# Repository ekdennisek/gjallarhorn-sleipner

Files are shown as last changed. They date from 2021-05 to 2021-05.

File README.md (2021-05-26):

# Gjallarhorn Sleipner

## Introduction

**This code is currently under development, and is not ready to be used yet.**
See the [TODO section](#todo)

The Gjallarhorn Sleipner is an open source Eurorack compatible step sequencer. Powered by an Atmel AVR ATmega32
running at 16 MHz, it features 2 CV/gate channels and 6 gate only channels for controlling percussion or similar.

## Programming the MCU

The firmware may be built by simply running

    make

Once the firmware `main.hex` is built, upload it to the MCU and set the correct fuse bits. The example below uses
avrdude on a Raspberry Pi to program the MCU (make sure that your `avrdude.conf` is setup correctly according to the
pins being used)

    avrdude -c linuxgpio -p atmega32 -v -U flash:w:main.hex
    avrdude -c linuxgpio -p atmega32 -v -U hfuse:w:0xC9:m
    avrdude -c linuxgpio -p atmega32 -v -U lfuse:w:0xEF:m

Please note that you will have to connect a 16 MHz crystal to the ATmega32 in order to use it once the fuses have been
programmed.

## Technical specs

### Gates

All eight gate outputs are 12 V with an output impedance of roughly 470 ohm.

### Clock

The clock output is 5 V. Just like the gates, its output impedance is roughly 470 ohm.

### CV

The two CV outputs are 0 V - 10 V and follows the 1 V per octave standard. A C4 note corresponds to 4 V.

## Usage

TODO

## TODO

The list below is far from an exhaustive list of what's coming, but the main features for a 1.0.0 version should all be
listed.

* Documentation: Write a usage and improve the technical specs section
* Firmware: Read the input state of the two command buttons, fé and úr
* Firmware: Allow a user to change the channel, tempo and note of the CV channels
* Firmware: Allow a user to set gate duration as a percentage of a step

## Changelog

TODO once version 1.0.0 has been achieved.

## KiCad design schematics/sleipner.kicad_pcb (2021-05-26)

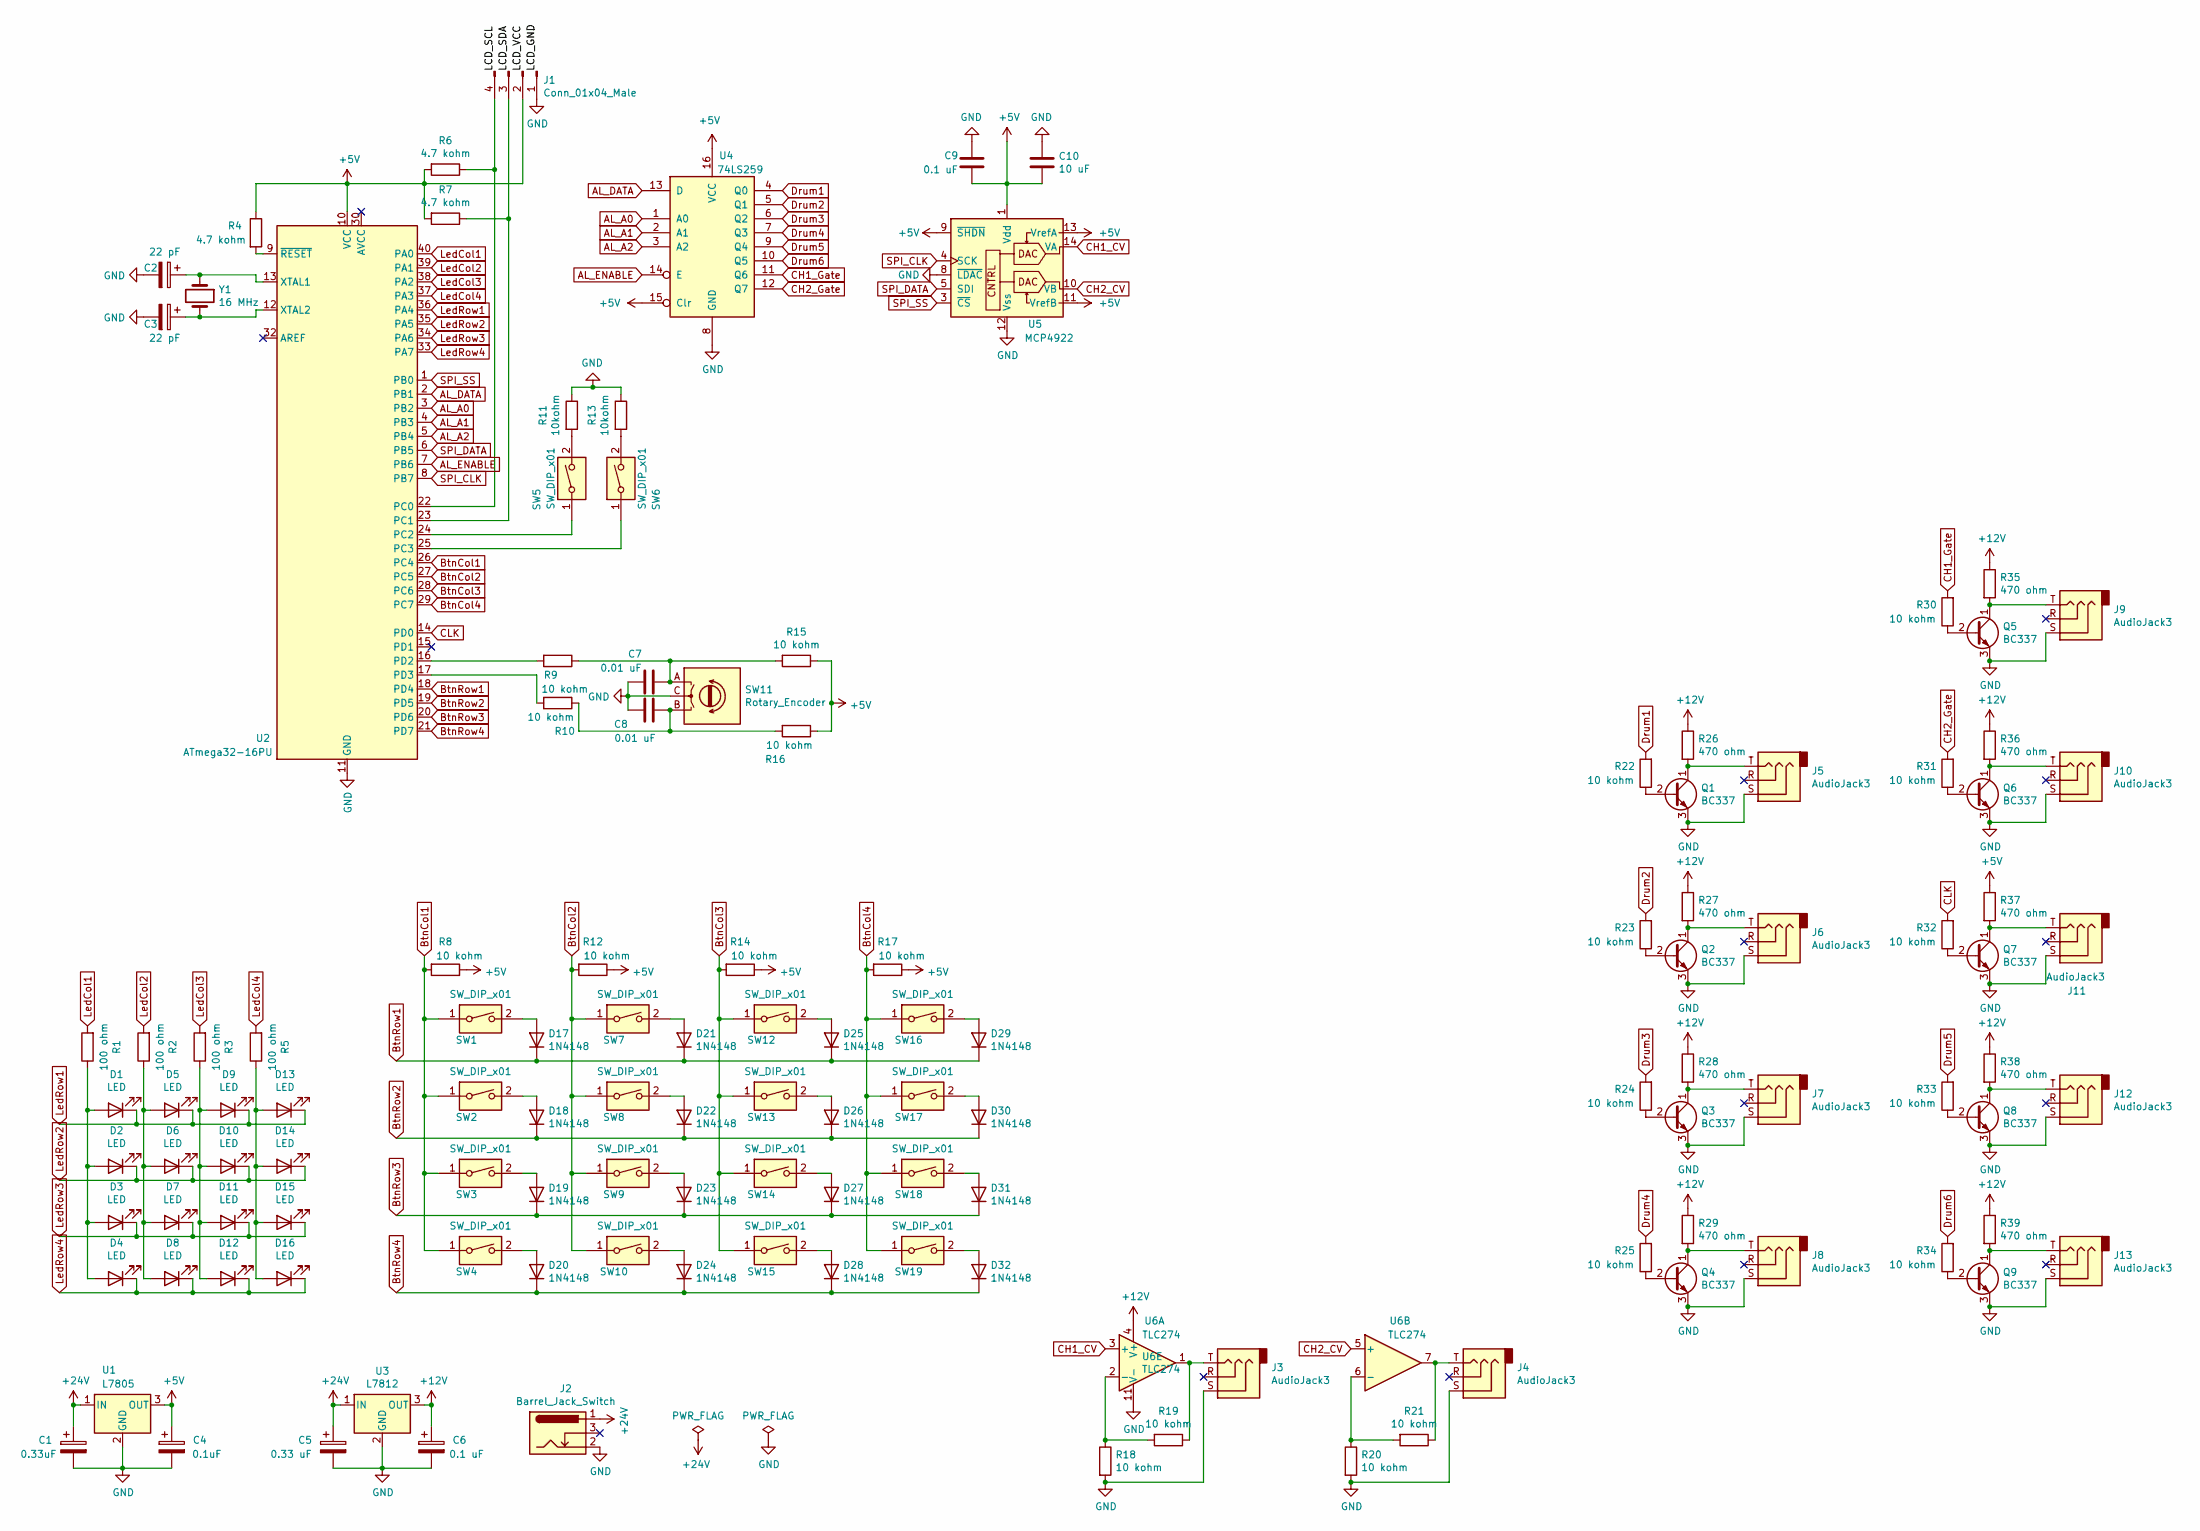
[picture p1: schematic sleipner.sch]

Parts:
C1: 0.33uF; CP_Radial_D5.0mm_P2.00mm
C2, C3: 22 pF; C_Disc_D5.0mm_W2.5mm_P5.00mm
C4: 0.1uF; C_Disc_D5.0mm_W2.5mm_P5.00mm
C5: 0.33 uF; CP_Radial_D5.0mm_P2.00mm
C6, C9: 0.1 uF; C_Disc_D5.0mm_W2.5mm_P5.00mm
C7, C8: 0.01 uF; C_Disc_D5.0mm_W2.5mm_P5.00mm
C10: 10 uF; CP_Radial_D5.0mm_P2.00mm
D1, D2, D3, D4, D5, D6, D7, D8, D9, D10, D11, D12, D13, D14, D15, D16: LED; LED_D3.0mm
D17, D18, D19, D20, D21, D22, D23, D24, D25, D26, D27, D28, D29, D30, D31, D32: 1N4148; D_DO-35_SOD27_P7.62mm_Horizontal
J1: Conn_01x04_Male; PinHeader_1x04_P2.54mm_Horizontal
J2: Barrel_Jack_Switch; BarrelJack_Horizontal
J3, J4, J5, J6, J7, J8, J9, J10, J11, J12, J13: AudioJack3; 3.55mmJack
Q1, Q2, Q3, Q4, Q5, Q6, Q7, Q8, Q9: BC337; TO-92_Inline
R1, R2, R3, R5: 100 ohm; R_Axial_DIN0309_L9.0mm_D3.2mm_P12.70mm_Horizontal
R4, R6, R7: 4.7 kohm; R_Axial_DIN0309_L9.0mm_D3.2mm_P12.70mm_Horizontal
R8, R9, R10, R12, R14, R15, R16, R17, R18, R19, R20, R21, R22, R23, R24, R25, R30, R31, R32, R33, R34: 10 kohm; R_Axial_DIN0309_L9.0mm_D3.2mm_P12.70mm_Horizontal
R11, R13: 10kohm; R_Axial_DIN0309_L9.0mm_D3.2mm_P12.70mm_Horizontal
R26, R27, R28, R29, R35, R36, R37, R38, R39: 470 ohm; R_Axial_DIN0309_L9.0mm_D3.2mm_P12.70mm_Horizontal
SW1, SW2, SW3, SW4, SW5, SW6, SW7, SW8, SW9, SW10, SW12, SW13, SW14, SW15, SW16, SW17, SW18, SW19: SW_DIP_x01; SW_PUSH-12mm
SW11: Rotary_Encoder; RotaryEncoder_Alps_EC12E_Vertical_H20mm
U1: L7805; TO-220-3_Horizontal_TabDown
U2: ATmega32-16PU; DIP-40_W15.24mm
U3: L7812; TO-220-3_Horizontal_TabDown
U4: 74LS259; DIP-16_W7.62mm
U5: MCP4922; DIP-14_W7.62mm
U6: TLC274; DIP-14_W7.62mm
Y1: 16 MHz; Crystal_HC49-4H_Vertical

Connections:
+5V: C4.1, C9.1, C10.1, J1.2, R4.1, R6.2, R7.2, R8.1, R12.1, R14.1, R15.1, R16.1, R17.1, R37.1, U1.3 (OUT), U2.10 (VCC), U4.15 (Clr), U4.16 (VCC), U5.1 (Vdd), U5.9 (~SHDN), U5.11 (VrefB), U5.13 (VrefA)
+12V: C6.1, R26.1, R27.1, R28.1, R29.1, R35.1, R36.1, R38.1, R39.1, U3.3 (OUT), U6.4 (V+)
+24V: C1.1, C5.1, J2.1, U1.1 (IN), U3.1 (IN)
AL_A0: U2.3 (PB2), U4.1 (A0)
AL_A1: U2.4 (PB3), U4.2 (A1)
AL_A2: U2.5 (PB4), U4.3 (A2)
AL_DATA: U2.2 (PB1), U4.13 (D)
AL_ENABLE: U2.7 (PB6), U4.14 (E)
BtnCol1: R8.2, SW1.1, SW2.1, SW3.1, SW4.1, U2.26 (PC4)
BtnCol2: R12.2, SW7.1, SW8.1, SW9.1, SW10.1, U2.27 (PC5)
BtnCol3: R14.2, SW12.1, SW13.1, SW14.1, SW15.1, U2.28 (PC6)
BtnCol4: R17.2, SW16.1, SW17.1, SW18.1, SW19.1, U2.29 (PC7)
BtnRow1: D17.1 (K), D21.1 (K), D25.1 (K), D29.1 (K), U2.18 (PD4)
BtnRow2: D18.1 (K), D22.1 (K), D26.1 (K), D30.1 (K), U2.19 (PD5)
BtnRow3: D19.1 (K), D23.1 (K), D27.1 (K), D31.1 (K), U2.20 (PD6)
BtnRow4: D20.1 (K), D24.1 (K), D28.1 (K), D32.1 (K), U2.21 (PD7)
CH1_CV: U5.14 (VA), U6.3 (+)
CH1_Gate: R30.2, U4.11 (Q6)
CH2_CV: U5.10 (VB), U6.5 (+)
CH2_Gate: R31.2, U4.12 (Q7)
CLK: R32.2, U2.14 (PD0)
Drum1: R22.2, U4.4 (Q0)
Drum2: R23.2, U4.5 (Q1)
Drum3: R24.2, U4.6 (Q2)
Drum4: R25.2, U4.7 (Q3)
Drum5: R33.2, U4.9 (Q4)
Drum6: R34.2, U4.10 (Q5)
GND: C1.2, C2.2, C3.2, C4.2, C5.2, C6.2, C7.2, C8.2, C9.2, C10.2, J1.1, J2.2, J3.S, J4.S, J5.S, J6.S, J7.S, J8.S, J9.S, J10.S, J11.S, J12.S, J13.S, Q1.3 (E), Q2.3 (E), Q3.3 (E), Q4.3 (E), Q5.3 (E), Q6.3 (E), Q7.3 (E), Q8.3 (E), Q9.3 (E), R11.1, R13.1, R18.2, R20.2, SW11.C, U1.2 (GND), U2.11 (GND), U2.31 (GND), U3.2 (GND), U4.8 (GND), U5.8 (~LDAC), U5.12 (Vss), U6.11 (V-)
LedCol1: R1.2, U2.40 (PA0)
LedCol2: R2.2, U2.39 (PA1)
LedCol3: R3.2, U2.38 (PA2)
LedCol4: R5.2, U2.37 (PA3)
LedRow1: D1.1 (K), D5.1 (K), D9.1 (K), D13.1 (K), U2.36 (PA4)
LedRow2: D2.1 (K), D6.1 (K), D10.1 (K), D14.1 (K), U2.35 (PA5)
LedRow3: D3.1 (K), D7.1 (K), D11.1 (K), D15.1 (K), U2.34 (PA6)
LedRow4: D4.1 (K), D8.1 (K), D12.1 (K), D16.1 (K), U2.33 (PA7)
unnamed: C2.1, U2.13 (XTAL1), Y1.1
unnamed: C3.1, U2.12 (XTAL2), Y1.2
unnamed: C7.1, R9.1, R15.2, SW11.A
unnamed: C8.1, R10.1, R16.2, SW11.B
unnamed: D1.2 (A), D2.2 (A), D3.2 (A), D4.2 (A), R1.1
unnamed: D5.2 (A), D6.2 (A), D7.2 (A), D8.2 (A), R2.1
unnamed: D9.2 (A), D10.2 (A), D11.2 (A), D12.2 (A), R3.1
unnamed: D13.2 (A), D14.2 (A), D15.2 (A), D16.2 (A), R5.1
unnamed: D17.2 (A), SW1.2
unnamed: D18.2 (A), SW2.2
unnamed: D19.2 (A), SW3.2
unnamed: D20.2 (A), SW4.2
unnamed: D21.2 (A), SW7.2
unnamed: D22.2 (A), SW8.2
unnamed: D23.2 (A), SW9.2
unnamed: D24.2 (A), SW10.2
unnamed: D25.2 (A), SW12.2
unnamed: D26.2 (A), SW13.2
unnamed: D27.2 (A), SW14.2
unnamed: D28.2 (A), SW15.2
unnamed: D29.2 (A), SW16.2
unnamed: D30.2 (A), SW17.2
unnamed: D31.2 (A), SW18.2
unnamed: D32.2 (A), SW19.2
unnamed: J1.3, R7.1, U2.23 (PC1)
unnamed: J1.4, R6.1, U2.22 (PC0)
unnamed: J3.T, R19.1, U6.1
unnamed: J4.T, R21.1, U6.7
unnamed: J5.T, Q1.1 (C), R26.2
unnamed: J6.T, Q2.1 (C), R27.2
unnamed: J7.T, Q3.1 (C), R28.2
unnamed: J8.T, Q4.1 (C), R29.2
unnamed: J9.T, Q5.1 (C), R35.2
unnamed: J10.T, Q6.1 (C), R36.2
unnamed: J11.T, Q7.1 (C), R37.2
unnamed: J12.T, Q8.1 (C), R38.2
unnamed: J13.T, Q9.1 (C), R39.2
unnamed: Q1.2 (B), R22.1
unnamed: Q2.2 (B), R23.1
unnamed: Q3.2 (B), R24.1
unnamed: Q4.2 (B), R25.1
unnamed: Q5.2 (B), R30.1
unnamed: Q6.2 (B), R31.1
unnamed: Q7.2 (B), R32.1
unnamed: Q8.2 (B), R33.1
unnamed: Q9.2 (B), R34.1
unnamed: R4.2, U2.9 (~RESET)
unnamed: R9.2, U2.16 (PD2)
unnamed: R10.2, U2.17 (PD3)
unnamed: R11.2, SW5.2
unnamed: R13.2, SW6.2
unnamed: R18.1, R19.2, U6.2 (-)
unnamed: R20.1, R21.2, U6.6 (-)
unnamed: SW5.1, U2.24 (PC2)
unnamed: SW6.1, U2.25 (PC3)
SPI_CLK: U2.8 (PB7), U5.4 (SCK)
SPI_DATA: U2.6 (PB5), U5.5 (SDI)
SPI_SS: U2.1 (PB0), U5.3 (~CS)

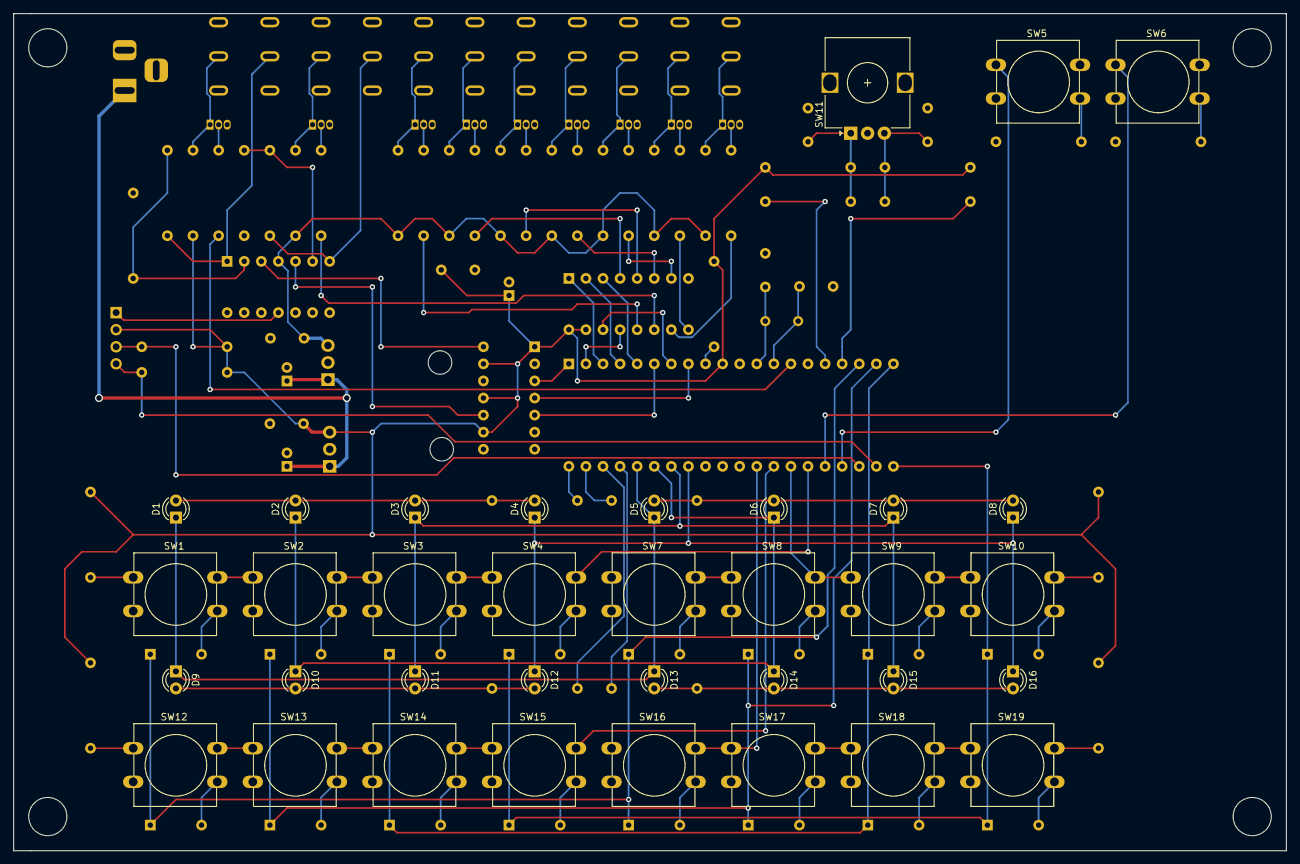
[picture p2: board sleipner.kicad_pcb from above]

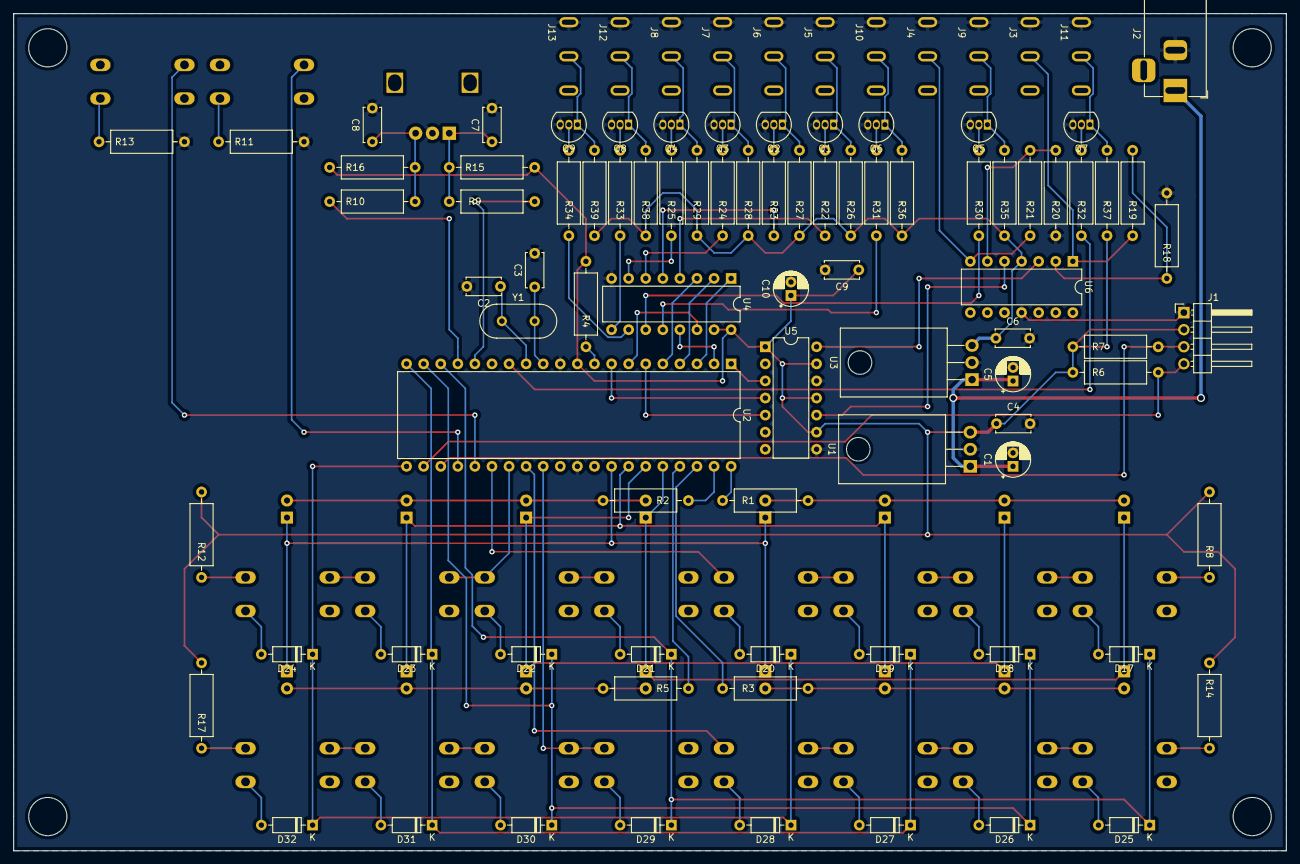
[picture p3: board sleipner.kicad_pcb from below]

Board: 2 copper layers, 189.2 x 124.5 mm, 129 parts (94 on the bottom side), 94 nets.

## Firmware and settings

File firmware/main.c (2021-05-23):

#include <avr/interrupt.h>
#include <avr/io.h>
#include <util/atomic.h>
#include <util/delay.h>

#include "dac.h"
#include "gate.h"
#include "lcd.h"
#include "spi.h"
#include "twi.h"
#include "usart.h"

#define PCF8574T_ADDRESS 0x27

#define ROTARY_ENCODER_MIN 0
#define ROTARY_ENCODER_MAX 255

volatile uint8_t rotary_encoder = 0;
volatile uint16_t milliseconds = 0;

ISR(INT0_vect) {
    uint8_t pin_b = PIND & (1<<PD3);
    if (pin_b && rotary_encoder > ROTARY_ENCODER_MIN) {
        rotary_encoder--;
    } else if (!pin_b && rotary_encoder < ROTARY_ENCODER_MAX) {
        rotary_encoder++;
    }
}

ISR(TIMER0_COMP_vect) {
    milliseconds++;
}

enum channel_type {
    synth,
    drum,
};

struct step {
    bool enabled;
    uint8_t note;
};

struct channel {
    enum channel_type type;
    struct step steps[16];
};

struct sequencer_state {
    uint8_t tempo;
    bool is_running;
    uint8_t current_step;
    uint8_t current_channel;
    struct channel channels[8];
};

void rotary_encoder_init();
void button_pressed(struct sequencer_state* sequencer, uint8_t button);
void button_released(struct sequencer_state* sequencer, uint8_t button);
uint16_t note_to_cv(uint8_t note);

int main() {
    usart_init();
    twi_init();
    lcd_init(PCF8574T_ADDRESS);
    rotary_encoder_init();
    spi_init();

    sei();

    lcd_turn_on(PCF8574T_ADDRESS);
    lcd_cursor_home(PCF8574T_ADDRESS);

    struct sequencer_state sequencer = {
        .tempo = 120,
        .is_running = false,
        .current_step = 0,
        .current_channel = 0,
        .channels = {
            (struct channel) { .type = synth, .steps = { (struct step) { .enabled = false, .note = 48 } } },
            (struct channel) { .type = synth, .steps = { (struct step) { .enabled = false, .note = 48 } } },
            (struct channel) { .type = drum, .steps = { (struct step) { .enabled = false, .note = 48 } } },
            (struct channel) { .type = drum, .steps = { (struct step) { .enabled = false, .note = 48 } } },
            (struct channel) { .type = drum, .steps = { (struct step) { .enabled = false, .note = 48 } } },
            (struct channel) { .type = drum, .steps = { (struct step) { .enabled = false, .note = 48 } } },
            (struct channel) { .type = drum, .steps = { (struct step) { .enabled = false, .note = 48 } } },
            (struct channel) { .type = drum, .steps = { (struct step) { .enabled = false, .note = 48 } } },
        },
    };

    // Setup test state
    sequencer.is_running = true;
    sequencer.tempo = 100;
    sequencer.channels[0].steps[0].enabled = true;
    sequencer.channels[0].steps[0].note = 0;
    sequencer.channels[0].steps[1].enabled = true;
    sequencer.channels[0].steps[1].note = 0;
    sequencer.channels[0].steps[2].enabled = true;
    sequencer.channels[0].steps[2].note = 0;
    sequencer.channels[0].steps[3].enabled = true;
    sequencer.channels[0].steps[3].note = 0;
    sequencer.channels[0].steps[4].enabled = true;
    sequencer.channels[0].steps[4].note = 48;
    sequencer.channels[0].steps[5].enabled = true;
    sequencer.channels[0].steps[5].note = 48;
    sequencer.channels[0].steps[6].enabled = true;
    sequencer.channels[0].steps[6].note = 48;
    sequencer.channels[0].steps[7].enabled = true;
    sequencer.channels[0].steps[7].note = 48;
    sequencer.channels[0].steps[8].enabled = false;
    sequencer.channels[0].steps[8].note = 119;
    sequencer.channels[0].steps[9].enabled = false;
    sequencer.channels[0].steps[9].note = 119;
    sequencer.channels[0].steps[10].enabled = false;
    sequencer.channels[0].steps[10].note = 119;
    sequencer.channels[0].steps[11].enabled = false;
    sequencer.channels[0].steps[11].note = 119;
    sequencer.channels[0].steps[12].enabled = false;
    sequencer.channels[0].steps[12].note = 48;
    sequencer.channels[0].steps[13].enabled = false;
    sequencer.channels[0].steps[13].note = 48;
    sequencer.channels[0].steps[14].enabled = false;
    sequencer.channels[0].steps[14].note = 48;
    sequencer.channels[0].steps[15].enabled = false;
    sequencer.channels[0].steps[15].note = 48;

    // LED matrix
    DDRA = 0;
    PORTA = 0;

    char lcd_line_one[16] = { 0 };
    char lcd_line_two[16] = { 0 };

    // timer0 - 1 ms timer
    TCCR0 = (1<<WGM01) | (1<<CS01) | (1<<CS00); // CTC mode, prescaler = 64. Results in a TCNT0 increase every 4 us.
    OCR0 = 250;
    TIMSK = (1<<OCIE0); // Enable timer interrupts

    uint16_t step_length_ms = (60.0 / (float) sequencer.tempo) * 1000.0;

    uint16_t button_state = 0;
    uint16_t last_read = 0xffff;
    uint16_t button_debounce = 0xffff;
    uint8_t repeated_reads = 0;

    while (1) {
        button_debounce = 0xffff;

        for (uint8_t column = 0; column < 4; column++) {
            // Button matrix, PC7...4 are inputs
            // Active column has pull-up resistor enabled, other columns are hi-z
            SFIOR = 0;
            DDRC = DDRC & 0xf;
            PORTC = (PORTC & 0xf) | (1<<(column+4));
            for (uint8_t row = 0; row < 4; row++) {
                // Button matrix, PD7...4 are outputs
                // Active row is low output, other rows are hi-z
                DDRD = (DDRD & 0xf) | (1<<(row+4));
                PORTD = PORTD & 0xf;

                // LED matrix
                uint8_t step = (column * 4) + row;
                bool step_is_active = sequencer.channels[sequencer.current_channel].steps[step].enabled;
                if (
                    (step == sequencer.current_step && !step_is_active) ||
                    (step != sequencer.current_step && step_is_active)
                ) {
                    DDRA = (1<<column) | (1<<(row+4));
                    PORTA = (1<<column);
                }

                // Read and debounce button state
                if (((PINC & 0xf0) & (1<<(column+4))) == 0) {
                    button_debounce &= ~(1<<(column * 4 + row));
                }
            }
        }

        if (button_debounce == last_read) {
            repeated_reads++;
            if (repeated_reads == 5) {
                for (uint8_t i = 0; i < 16; i++) {
                    uint8_t last_button_state = button_state & (1<<i);
                    uint8_t current_button_state = (~button_debounce) & (1<<i);
                    if (current_button_state > last_button_state) {
                        button_pressed(&sequencer, i);
                    } else if (current_button_state < last_button_state) {
                        button_released(&sequencer, i);
                    }
                }
                button_state = ~button_debounce;
            }
        } else {
            last_read = button_debounce;
            repeated_reads = 0;
        }

        // TODO Read and debounce fé and úr buttons

        // Advance if sequencer is running
        if (sequencer.is_running) {
            ATOMIC_BLOCK(ATOMIC_FORCEON) {
                if (milliseconds > step_length_ms) {
                    sequencer.current_step = (sequencer.current_step + 1) % 16;
                    milliseconds -= step_length_ms;

                    // Update CV
                    dac_send(0, note_to_cv(sequencer.channels[0].steps[sequencer.current_step].note));
                    dac_send(1, note_to_cv(sequencer.channels[1].steps[sequencer.current_step].note));
                    // Update gates
                    gate_set(SYNTH1, sequencer.channels[0].steps[sequencer.current_step].enabled);
                    gate_set(SYNTH2, sequencer.channels[1].steps[sequencer.current_step].enabled);
                    gate_set(DRUM1, sequencer.current_step % 2);
                    // TODO Drum0-5

                    snprintf(lcd_line_one, 16, "CH %02u", sequencer.current_channel + 1);
                    snprintf(lcd_line_two, 16, "STEP %02u", sequencer.current_step + 1);
                    lcd_send_lines(lcd_line_one, lcd_line_two, PCF8574T_ADDRESS);
                }
            }
        }
    }

    return 0;
}

void rotary_encoder_init() {
    DDRD = 0;
    PORTD = 0;
    MCUCR = (1<<ISC01) | (1<<ISC00);
    GICR = (1<<INT0);
}

void button_pressed(struct sequencer_state* sequencer, uint8_t button) {
    // TODO
}

void button_released(struct sequencer_state* sequencer, uint8_t button) {
    sequencer->channels[sequencer->current_channel].steps[button].enabled ^= true;
}

uint16_t note_to_cv(uint8_t note) {
    double voltage = ((double)note / 119.0) * 5.0;
    return (voltage * 4095.0) / 5.0;
}

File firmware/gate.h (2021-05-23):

#include <stdbool.h>
#include <stdint.h>

#define DRUM1 0
#define DRUM2 1
#define DRUM3 2
#define DRUM4 3
#define DRUM5 4
#define DRUM6 5
#define SYNTH1 6
#define SYNTH2 7

void gate_init();
void gate_set(uint8_t gate, bool on);

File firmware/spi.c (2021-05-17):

#include "spi.h"

void spi_init() {
    DDRB =
        (1<<PB7) | // SCK
        (1<<PB5) | // MOSI
        (1<<PB4) | // Configure SS as output to avoid inteference from floating reads
        (1<<PB0);  // Slave SS
    PORTB = (1<<PB0);
    SPCR = (1<<SPE) | (1<<MSTR);
    SPSR = (1<<SPI2X);
}

void spi_send_bytes(uint8_t* bytes, uint8_t num_bytes) {
    PORTB &= ~(1<<PB0);
    for (uint8_t i = 0; i < num_bytes; i++) {
        SPDR = bytes[i];
        while (!(SPSR & (1<<SPIF)));
    }
    PORTB |= (1<<PB0);
}

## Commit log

2021-05-09 Use correct length for snprintf
    [main.c]
2021-05-09 Add rotary encoder input on PD2 and PD3
2021-05-16 Read input from button matrix and light up relevant LEDs
2021-05-23 Add schematics
    [MCP4922-E_P.step, TLC274CN.step, sleipner.kicad_pcb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]
2021-05-26 Update schematics and add PCB layout
    [sleipner.sch]
2021-05-26 Redo the PCB
    [sleipner.kicad_pcb, sleipner.sch]
2021-05-26 Update README and delete unused files
    [MCP4922-E_P.step, TLC274CN.step]
